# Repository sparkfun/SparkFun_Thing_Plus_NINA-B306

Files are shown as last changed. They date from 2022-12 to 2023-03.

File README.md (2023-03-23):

# SparkFun Thing Plus - NINA-B306

SparkFun Thing Plus - NINA-B306 (https://www.sparkfun.com/products/20854)

[SparkFun Thing Plus - NINA-B306 (WRL-20854)](https://www.sparkfun.com/products/20854)

The SparkFun Thing Plus - NINA-B306 offers a unique combination development platform in the Thing Plus form factor featuring the NINA-B306 from u-blox<sup>&trade;</sup>, the ISM330DHCX 6 DoF IMU from STMicroelectronics<sup>&trade;</sup> and the BME280 atmospheric sensor from Bosch Sensortec<sup>&trade;</sup>.

The NINA-B306 is a combination Bluetooth<sup>&trade;</sup> 5 module with an Arm<sup>&reg;</sup> Cortex<sup>&reg;</sup>-M4 processor. The NINA-B306 features an integrated PCB antenna removing the need for any external antenna. It includes 1 MB Flash and 250 kB RAM.

The BME280 combined humidity and pressure sensor measures barometric pressure, humidity and ambient temperature in a small package. The sensor measures pressure from 300 to 1100 hPa and has a full temperature accuracy range from 0 to 65&deg;C. The sensor communicates with the NINA-B306 over I<sup>2</sup>C.

The ISM330DHCX 6DoF IMU is a high-performance 3D digital accelerometer and 3D digital gyroscope tailored for Industry 4.0. The IMU has full scale user selectable acceleration ranges of &plusmn;2/&plusmn;4/&plusmn;8/&plusmn;16g and wide angular rate ranges of &plusmn;125/&plusmn;250/&plusmn;500/&plusmn;1000/&plusmn;2000/&plusmn;4000dps. The ISM330DHCX has embedded features including Machine Learning Core<sup><a href="#IMU_Mode">1</a></b></sup>, programmable FSM, FIFO, sensor hub, event decoding, and interrupts.

## Repository Contents

- **/Documentation** - Data sheets, additional product information
- **/Firmware** - Example code
- **/Hardware** - Eagle design files (.brd, .sch)
- **/Production** - Production panel files (.brd)

## Documentation

- **[BME280 Library](https://github.com/sparkfun/SparkFun_BME280_Arduino_Library)** - Arduino library for the BME280.
- **[ISM330DHCX Library](https://github.com/sparkfun/SparkFun_6DoF_ISM330DHCX_Arduino_Library)** - Arduino library for the ISM330DHCX.
- **[MAX17048 Library](https://github.com/sparkfun/SparkFun_MAX1704x_Fuel_Gauge_Arduino_Library)** - Arduino library for the MAX1704X.
- **[Hookup Guide](https://learn.sparkfun.com/tutorials/sparkfun-thing-plus---nina-b306-hookup-guide)** - Basic hookup guide for the SparkFun Thing Plus - NINA-B306.

## Product Versions

- [WRL-20854](https://www.sparkfun.com/products/20854) - Initial release of the SparkFun Thing Plus - NINA-B306.

## License Information

This product is _**open source**_!

Please review the LICENSE.md file for license information.

If you have any questions or concerns on licensing, please contact technical support on our [SparkFun forums](https://forum.sparkfun.com/viewforum.php?f=152).

Distributed as-is; no warranty is given.

- Your friends at SparkFun.

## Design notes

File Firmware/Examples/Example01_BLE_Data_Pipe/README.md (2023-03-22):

# Example01 BLE Data Pipe Demo arduino-cli flash command

From `$REPO/Firmware/Examples/Example01_BLE_Data_Pipe`:

## Locally downloaded Repo and Library

```bash
arduino-cli.exe compile --library /absolute/path/to/library/SparkFun_Thing_Plus_NINA-B306/libraries/SparkFunBLEService -b arduino-git:Adafruit_nRF52_Arduino:sfe_thingplus_ninab306 -e --port $COMPORT --upload Example01_BLE_Data_Pipe.ino
```

## Arduino Library

```bash
arduino-cli.exe compile -b adafruit:nrf52:sfe_thingplus_ninab306 -e --port $COMPORT --upload Example01_BLE_Data_Pipe.ino
```

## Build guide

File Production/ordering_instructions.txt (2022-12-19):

panel size, 131x154mm
PCB thickness, 1.6mm
number of layers, 4
soldermask color, Red
silkscreen color, White
oz copper, 1oz
finish, HASL lead free
stencils, top+bottom
pcs per panel, 10
min trace width, 0.1500mm / 0.0059in
min drill size, 0.3000mm / 0.0118in
filename to layer stackup 1/2/3/4: GTL, GL2, GL3, GBL

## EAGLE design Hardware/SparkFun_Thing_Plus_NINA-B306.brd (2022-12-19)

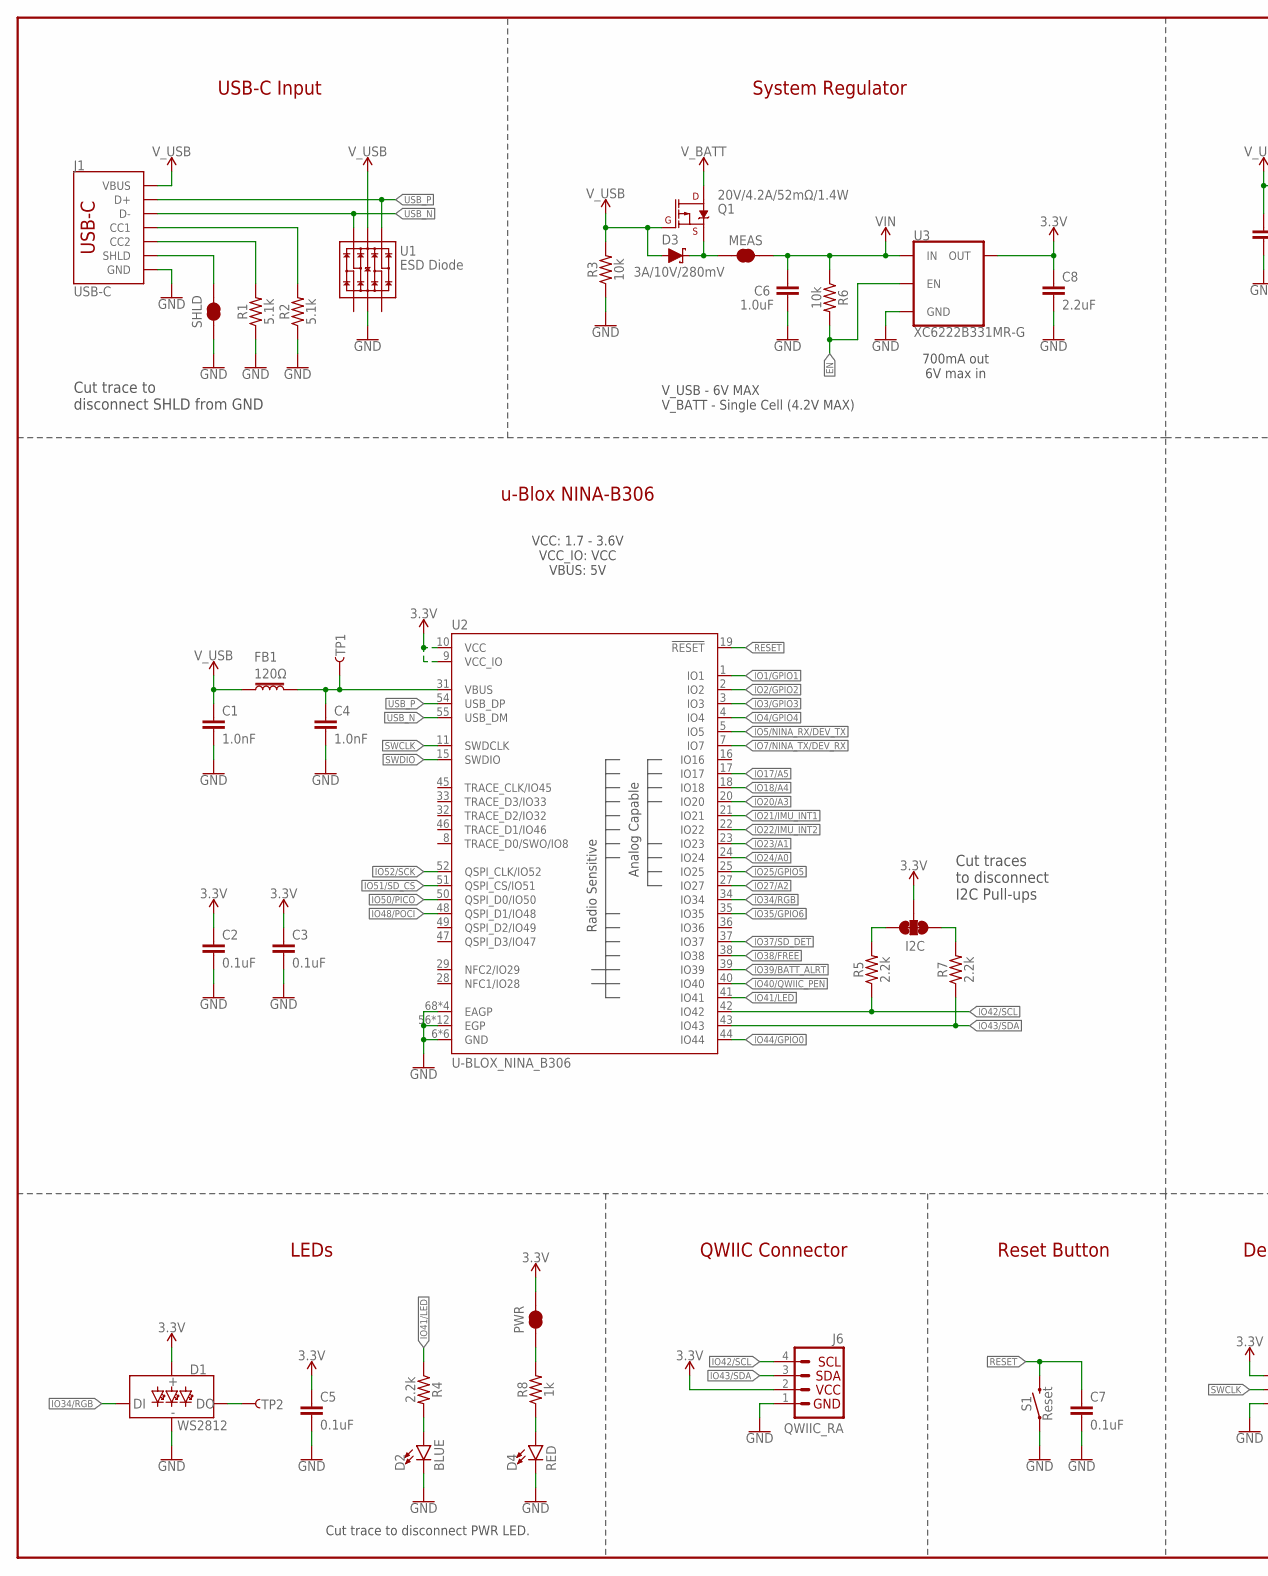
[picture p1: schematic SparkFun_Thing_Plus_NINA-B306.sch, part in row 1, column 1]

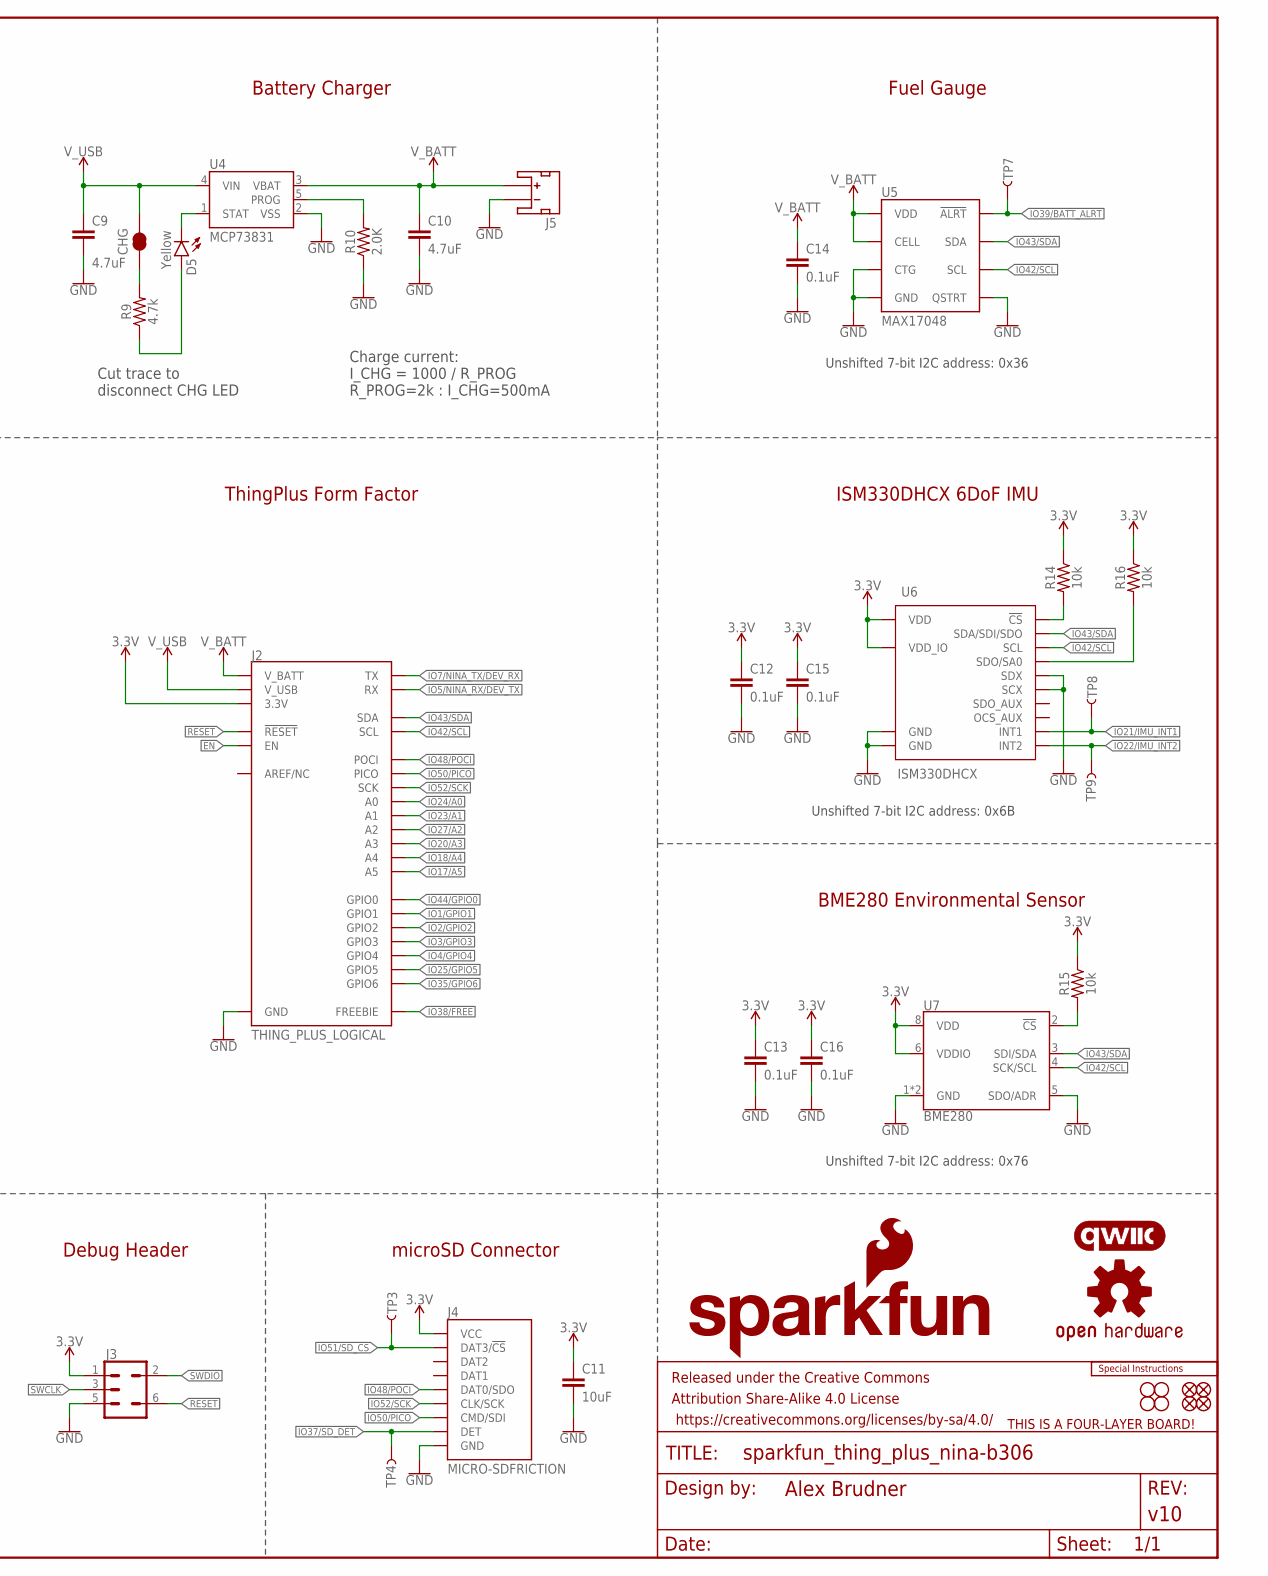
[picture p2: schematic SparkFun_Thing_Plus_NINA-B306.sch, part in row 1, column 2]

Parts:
C1, C4: 1.0nF; 0402-TIGHT
C2, C3, C5, C7, C12, C13, C14, C15, C16: 0.1uF; 0402-TIGHT
C6: 1.0uF; 0402-TIGHT
C8: 2.2uF; 0402-TIGHT
C9, C10: 4.7uF; 0402-TIGHT
C11: 10uF; 0402-TIGHT
CHG: JUMPER-SMT_2_NC_TRACE_SILK; SMT-JUMPER_2_NC_TRACE_SILK
D1: WS2812; WS2812-2020
D2: BLUE; LED-0603
D3: 3A/10V/280mV; SOD-323
D4: RED; LED-0603
D5: Yellow; LED-0603
FB1: 120Ω; 0402
FD1, FD2, FD3, FD4: FIDUCIALUFIDUCIAL; FIDUCIAL-MICRO
FRAME1: FRAME-LEDGER; CREATIVE_COMMONS
H1, H2, H3, H4: STAND-OFFTIGHT; STAND-OFF-TIGHT
I2C: JUMPER-SMT_3_2-NC_TRACE_SILK; SMT-JUMPER_3_2-NC_TRACE_SILK
J1: USB-C; USB-C-16P-4LAYER-ISOLATED
J2: THING_PLUS_LOGICAL; THING_PLUS
J3: CONN_03X2_NO4; PAD_05_03X2_TP_NO4
J4: MICRO-SDFRICTION; MICROSD_TINY
J5: JST_2MM_MALE; JST-2-SMD
J6: QWIIC_RA; JST04_1MM_RA
LOGO1: SFE_LOGO_NAME_FLAME.1_INCH; SFE_LOGO_NAME_FLAME_.1
LOGO2: FOUR_LAYER_WARNING
LOGO3: SPECIAL_INSTRUCTIONS-ORDERING; ORDERING_INSTRUCTIONS
LOGO4: QWIIC_LOGO_4MM; QWIIC_4MM
LOGO5: OSHW-LOGOMINI; OSHW-LOGO-MINI
MEAS: JUMPER-COMBO_2_NC_TRACE; COMBO-JUMPER_2_NC_TRACE
PWR: JUMPER-SMT_2_NC_TRACE_SILK; SMT-JUMPER_2_NC_TRACE_SILK
Q1: 20V/4.2A/52mΩ/1.4W; SOT23-3
R1, R2: 5.1k; 0402-TIGHT
R3, R6, R14, R15, R16: 10k; 0402-TIGHT
R4, R5, R7: 2.2k; 0402-TIGHT
R8: 1k; 0402-TIGHT
R9: 4.7k; 0402-TIGHT
R10: 2.0K; 0402-TIGHT
S1: Reset; TACTILE_SWITCH_SMD_4.6X2.8MM
SHLD: JUMPER-SMT_2_NC_TRACE_SILK; SMT-JUMPER_2_NC_TRACE_SILK
TP1, TP2, TP3, TP4, TP7, TP8, TP9: TEST-POINT3X5; PAD.03X.05
U1: ESD Diode; SOT-23-6
U2: U-BLOX_NINA_B306; NINA_B306
U3: XC6222B331MR-G; SOT23-5
U4: MCP73831; SOT23-5
U5: MAX17048; DFN-8
U6: ISM330DHCX; LGA-14L
U7: BME280; LGA-8-2.5X2.5

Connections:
3.3V: C2.1, C3.1, C5.1, C8.1, C11.1, C12.1, C13.1, C15.1, C16.1, D1.VCC, I2C.2, J2.27 (3.3V), J3.1, J4.4 (VCC), J6.2, PWR.2, R14.1, R15.1, R16.1, U2.9 (VCC_IO), U2.10 (VCC), U3.5 (OUT), U6.P5 (VDD_IO), U6.P8 (VDD), U7.6 (VDDIO), U7.8 (VDD)
!RESET!: C7.1, J2.28 (!RESET), J3.6, S1.3 (2), S1.4 (2), U2.19 (!RESET!)
EN: J2.11 (EN), R6.2, U3.3 (EN)
GND: C1.2, C2.2, C3.2, C4.2, C5.2, C6.2, C7.2, C8.2, C9.2, C10.2, C11.2, C12.2, C13.2, C14.2, C15.2, C16.2, D1.GND, D2.C, D4.C, J1.GND, J1.GND2 (GND), J2.25 (GND), J3.5, J4.6 (GND), J4.GND1 (GND), J4.GND2 (GND), J4.GND3 (GND), J4.GND4 (GND), J4.GND5 (GND), J4.GND6 (GND), J5.1 (-), J6.1, R1.1, R2.1, R3.1, R10.1, S1.1, S1.2 (1), SHLD.1, U1.2 (VSS), U2.6 (GND), U2.12 (GND), U2.14 (GND), U2.26 (GND), U2.30 (GND), U2.53 (GND), U2.56 (EGP), U2.57 (EGP), U2.58 (EGP), U2.59 (EGP), U2.60 (EGP), U2.61 (EGP), U2.62 (EGP), U2.63 (EGP), U2.64 (EGP), U2.65 (EGP), U2.66 (EGP), U2.67 (EGP), U2.68 (EAGP), U2.69 (EAGP), U2.70 (EAGP), U2.71 (EAGP), U3.2 (GND), U4.2 (VSS), U5.1 (CTG), U5.4 (GND), U5.6 (QSTRT), U5.9 (GND), U6.P2 (SDX), U6.P3 (SCX), U6.P6 (GND), U6.P7 (GND), U7.1 (GND), U7.5 (SDO/ADR), U7.7 (GND)
IO1/GPIO1: J2.8 (GPIO1), U2.1 (IO1)
IO2/GPIO2: J2.7 (GPIO2), U2.2 (IO2)
IO3/GPIO3: J2.6 (GPIO3), U2.3 (IO3)
IO4/GPIO4: J2.5 (GPIO4), U2.4 (IO4)
IO5/NINA_RX/DEV_TX: J2.15 (RX), U2.5 (IO5)
IO7/NINA_TX/DEV_RX: J2.14 (TX), U2.7 (IO7)
IO17/A5: J2.19 (A5), U2.17 (IO17)
IO18/A4: J2.20 (A4), U2.18 (IO18)
IO20/A3: J2.21 (A3), U2.20 (IO20)
IO21/IMU_INT1: TP8.1, U2.21 (IO21), U6.P4 (INT1)
IO22/IMU_INT2: TP9.1, U2.22 (IO22), U6.P9 (INT2)
IO23/A1: J2.23 (A1), U2.23 (IO23)
IO24/A0: J2.24 (A0), U2.24 (IO24)
IO25/GPIO5: J2.4 (GPIO5), U2.25 (IO25)
IO27/A2: J2.22 (A2), U2.27 (IO27)
IO34/RGB: D1.DI, U2.34 (IO34)
IO35/GPIO6: J2.3 (GPIO6), U2.35 (IO35)
IO37/SD_DET: J4.9 (DET), TP4.1, U2.37 (IO37)
IO38/FREE: J2.13 (FREEBIE), U2.38 (IO38)
IO39/!BATT_ALRT!: TP7.1, U2.39 (IO39), U5.5 (!ALRT)
IO40/QWIIC_!PEN!: U2.40 (IO40)
IO41/LED: R4.1, U2.41 (IO41)
IO42/SCL: J2.2 (SCL), J6.4, R5.1, U2.42 (IO42), U5.7 (SCL), U6.P13 (SCL), U7.4 (SCK/SCL)
IO43/SDA: J2.1 (SDA), J6.3, R7.1, U2.43 (IO43), U5.8 (SDA), U6.P14 (SDA/SDI/SDO), U7.3 (SDI/SDA)
IO44/GPIO0: J2.9 (GPIO0), U2.44 (IO44)
IO48/POCI: J2.16 (POCI), J4.7 (DAT0/SDO), U2.48 (QSPI_D1/IO48)
IO50/PICO: J2.17 (PICO), J4.3 (CMD/SDI), U2.50 (QSPI_D0/IO50)
IO51/SD_!CS!: J4.2 (DAT3/!CS!), TP3.1, U2.51 (QSPI_CS/IO51)
IO52/SCK: J2.18 (SCK), J4.5 (CLK/SCK), U2.52 (QSPI_CLK/IO52)
unnamed: J1.B5 (CC2), R1.2
unnamed: J1.A5 (CC1), R2.2
unnamed: D5.A, R9.1
unnamed: D5.C, U4.1 (STAT)
unnamed: R10.2, U4.5 (PROG)
unnamed: CHG.1, R9.2
unnamed: D4.A, R8.1
unnamed: PWR.1, R8.2
unnamed: D3.C, MEAS.1, MEAS.3 (1), Q1.2 (S)
unnamed: D1.DO, TP2.1
unnamed: R15.2, U7.2 (!CS)
unnamed: D2.A, R4.2
unnamed: R14.2, U6.P12 (!CS!)
unnamed: R16.2, U6.P1 (SDO/SA0)
unnamed: C4.1, FB1.2, TP1.1, U2.31 (VBUS)
SCL_PU_PWR: I2C.3, R5.2
SDA_PU_PWR: I2C.1, R7.2
SHLD: J1.SHLD1 (SHLD), J1.SHLD2 (SHLD), J1.SHLD3 (SHLD), J1.SHLD4 (SHLD), J1.SHLD5 (SHLD), J1.SHLD6 (SHLD), J1.SHLD7 (SHLD), J1.SHLD8 (SHLD), SHLD.2
SWCLK: J3.3, U2.11 (SWDCLK)
SWDIO: J3.2, U2.15 (SWDIO)
USB_N: J1.A7 (D-), J1.B7 (D-), U1.6 (IO4), U2.55 (USB_DM)
USB_P: J1.A6 (D+), J1.B6 (D+), U1.4 (IO3), U2.54 (USB_DP)
VIN: C6.1, MEAS.2, MEAS.4 (2), R6.1, U3.1 (IN)
V_BATT: C10.1, C14.1, J2.12 (V_BATT), J5.2 (+), Q1.3 (D), U4.3 (VBAT), U5.2 (CELL), U5.3 (VDD)
V_USB: C1.1, C9.1, CHG.2, D3.A, FB1.1, J1.VBUS1 (VBUS), J1.VBUS2 (VBUS), J2.10 (V_USB), Q1.1 (G), R3.2, U1.5 (VCC), U4.4 (VIN)

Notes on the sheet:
Battery Charger
Cut trace to disconnect CHG LED
Charge current: I_CHG = 1000 / R_PROG R_PROG=2k : I_CHG=500mA
System Regulator
700mA out 6V max in
V_USB - 6V MAX V_BATT - Single Cell (4.2V MAX)
USB-C Input
Fuel Gauge
Unshifted 7-bit I2C address: 0x36
Cut trace to disconnect SHLD from GND
microSD Connector
Debug Header
LEDs
Reset Button
u-Blox NINA-B306
ThingPlus Form Factor
QWIIC Connector
Cut traces to disconnect I2C Pull-ups
BME280 Environmental Sensor
Unshifted 7-bit I2C address: 0x76
Unshifted 7-bit I2C address: 0x6B
ISM330DHCX 6DoF IMU
VCC: 1.7 - 3.6V VCC_IO: VCC VBUS: 5V
Cut trace to disconnect PWR LED.

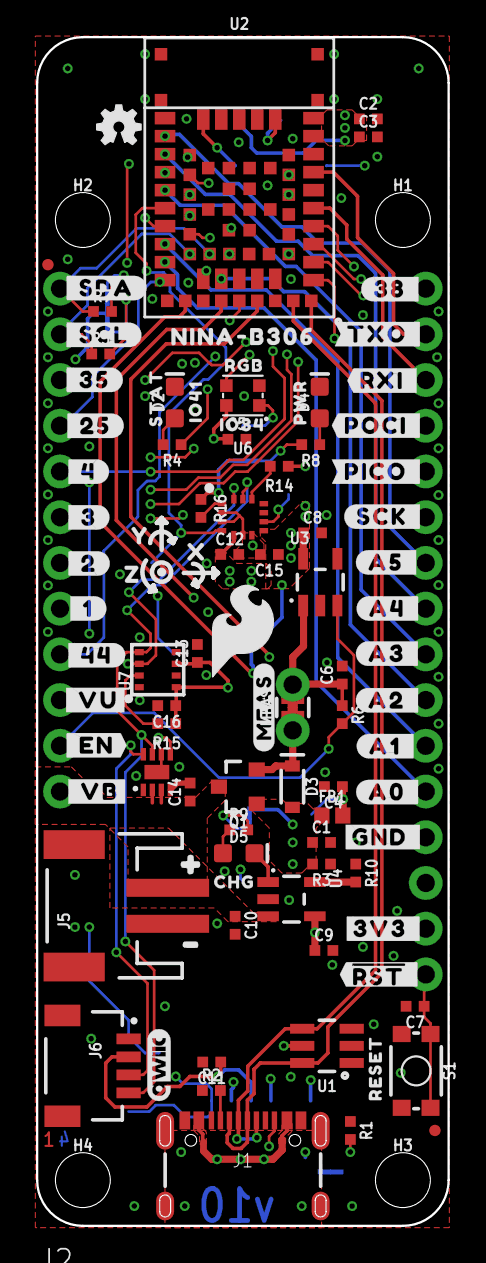
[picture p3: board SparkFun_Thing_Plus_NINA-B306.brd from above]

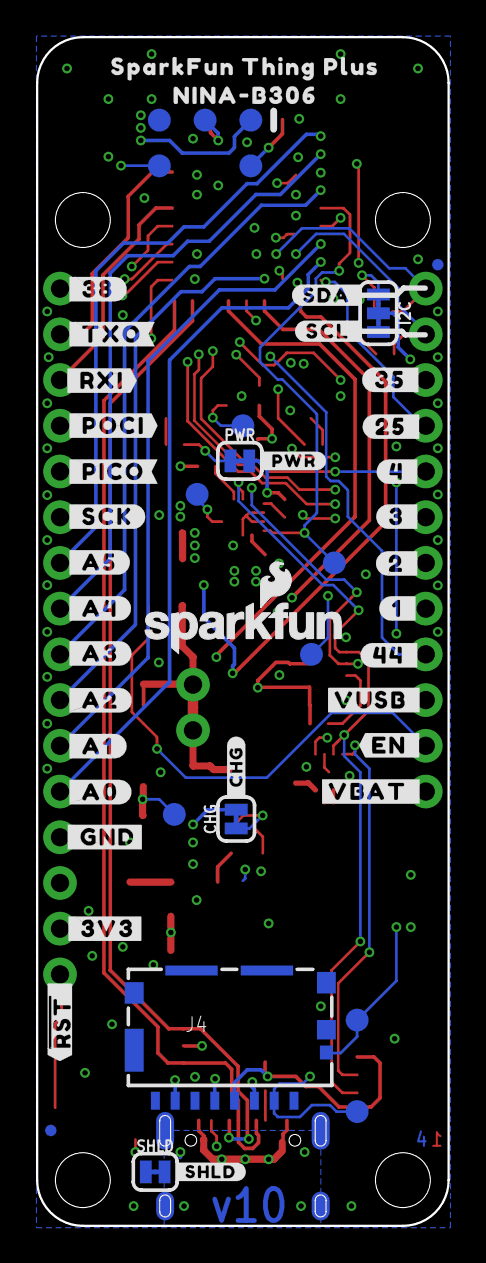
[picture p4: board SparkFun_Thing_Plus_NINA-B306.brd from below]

Board: 4 copper layers, 22.9 x 66.0 mm, 151 parts (49 on the bottom side), 57 nets.

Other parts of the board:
U$1: SFE_LOGO_FLAME_STOP_.1
U$2: SFE_LOGO_FLAME_.2
U$3: #_VU#0
U$4: #_EN#47
U$5: #3V3_#0
U$6: #_44#49
U$7: #_1#49
U$8: #_2#49
U$9: #_3#49
U$10: #_4#49
U$11: #_25#49
U$12: #_35#0
U$13: #_SCL#49
U$14: RESET0
U$16: #GND_#53
U$17: #A0_#54
U$18: #A1_#54
U$19: #A2_#54
U$20: #A3_#54
U$21: #A4_#54
U$22: #A5_#54
U$23: #SCK_#54
U$24: #PICO_#60
U$25: #POCI_#61
U$26: #TXO_#57
U$27: #RXI_#59
U$28: #38_#60
U$29: #_SDA#68
U$30: #_CHG#30707
U$31: #_3V3#0
U$32: #_GND#70
U$33: #_A0#71
U$34: #_A1#71
U$35: #_A2#71
U$36: #_A3#71
U$37: #_A4#71
U$38: #_A5#71
U$39: #_SCK#71
U$40: #_PICO#72
U$41: #_POCI#73
U$42: #_TXO#74
U$43: #_RXI#75
U$44: #_38#76
U$45: #35_#0
U$46: #25_#79
U$47: #4_#79
U$48: #3_#79
U$49: #2_#79
U$50: #1_#79
U$51: #44_#79
U$52: #VBAT_#0
U$53: #EN_#80
U$54, U$74: ##RST#_#0
U$55: #SDA_#82
U$56: #SCL_#85
U$57: #_PWR#90
U$58: #VUSB_#0
U$59: #_SHLD#93
U$60: SPARKFUN_THING_PLUS96
U$61: NINA#B30697
U$62: #MEAS#30701
U$63: #_VB#0
U$64: RGB30710
U$65: STAT30711
U$66: PWR30712
U$67: NINA#B30630713
U$68: X2114
U$69: Y2115
U$70: Z2116
U$71: IO414130630715
U$72: IO34414130630716
U$73: CHG0
U$75: #3
U$76: #4

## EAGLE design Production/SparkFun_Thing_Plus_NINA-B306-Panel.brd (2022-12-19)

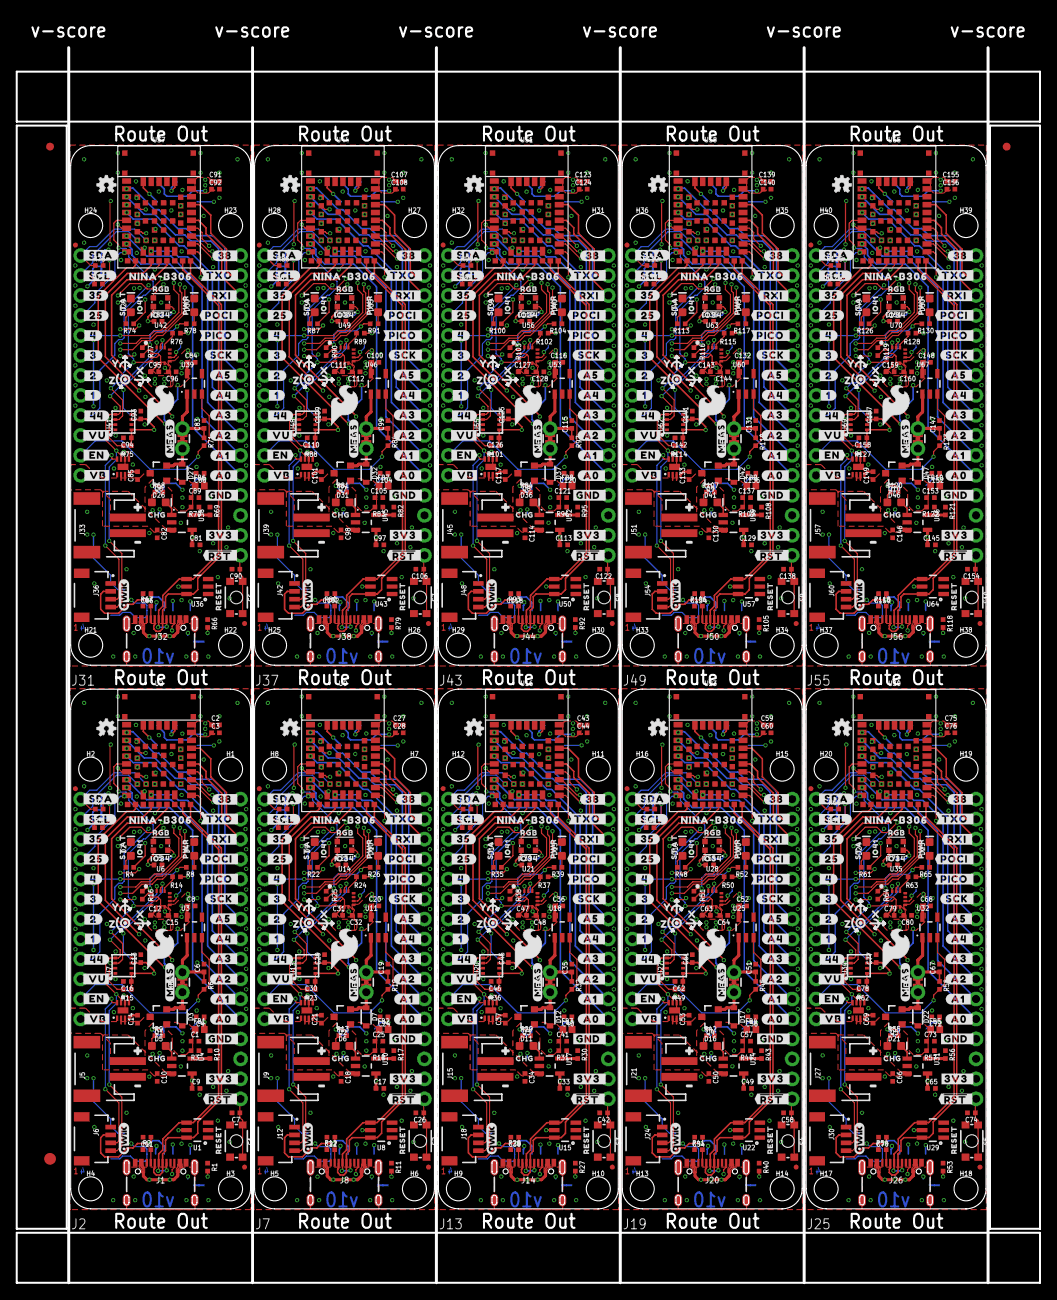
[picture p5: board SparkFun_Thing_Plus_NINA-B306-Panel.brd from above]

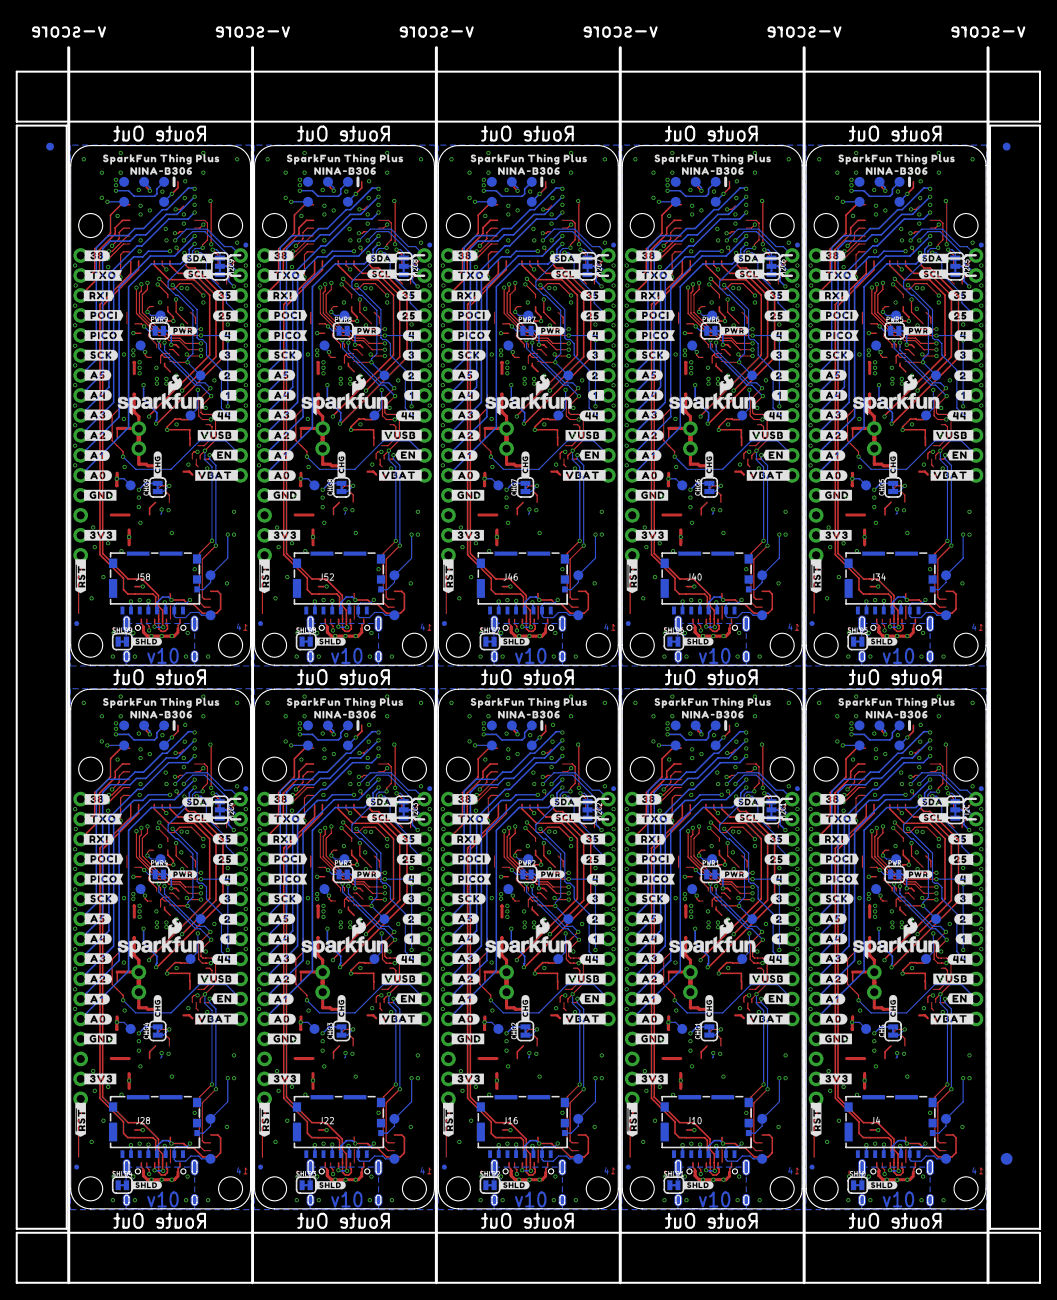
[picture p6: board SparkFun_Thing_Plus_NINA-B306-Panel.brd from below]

Board: 4 copper layers, 130.0 x 157.0 mm, 1506 parts (493 on the bottom side), 570 nets.

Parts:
C1, C4, C24, C25, C40, C41, C56, C57, C72, C73, C88, C89, C104, C105, C120, C121, C136, C137, C152, C153: 1.0nF; 0402-TIGHT
C2, C3, C5, C7, C12, C13, C14, C15, C16, C21, C23, C26, C27, C28, C29, C30, C31, C32, C37, C39, C42, C43, C44, C45, C46, C47, C48, C53, C55, C58, C59, C60, C61, C62, C63, C64, C69, C71, C74, C75, C76, C77, C78, C79, C80, C85, C87, C90, C91, C92, C93, C94, C95, C96, C101, C103, C106, C107, C108, C109, C110, C111, C112, C117, C119, C122, C123, C124, C125, C126, C127, C128, C133, C135, C138, C139, C140, C141, C142, C143, C144, C149, C151, C154, C155, C156, C157, C158, C159, C160: 0.1uF; 0402-TIGHT
C6, C19, C35, C51, C67, C83, C99, C115, C131, C147: 1.0uF; 0402-TIGHT
C8, C20, C36, C52, C68, C84, C100, C116, C132, C148: 2.2uF; 0402-TIGHT
C9, C10, C17, C18, C33, C34, C49, C50, C65, C66, C81, C82, C97, C98, C113, C114, C129, C130, C145, C146: 4.7uF; 0402-TIGHT
C11, C22, C38, C54, C70, C86, C102, C118, C134, C150: 10uF; 0402-TIGHT
CHG, CHG1, CHG2, CHG3, CHG4, CHG5, CHG6, CHG7, CHG8, CHG9: JUMPER-SMT_2_NC_TRACE_SILK; SMT-JUMPER_2_NC_TRACE_SILK
D1, D8, D13, D18, D23, D28, D33, D38, D43, D48: WS2812; WS2812-2020
D2, D9, D14, D19, D24, D29, D34, D39, D44, D49: BLUE; LED-0603
D3, D7, D12, D17, D22, D27, D32, D37, D42, D47: 3A/10V/280mV; SOD-323
D4, D10, D15, D20, D25, D30, D35, D40, D45, D50: RED; LED-0603
D5, D6, D11, D16, D21, D26, D31, D36, D41, D46: Yellow; LED-0603
E$1, E$2, E$3, E$4: FIDUCIAL-1X2
E$5, E$6: FIDUCIAL-1.5X3
FB1, FB2, FB3, FB4, FB5, FB6, FB7, FB8, FB9, FB10: 120Ω; 0402
FD1, FD2, FD3, FD4, FD5, FD6, FD7, FD8, FD9, FD10, FD11, FD12, FD13, FD14, FD15, FD16, FD17, FD18, FD19, FD20, FD21, FD22, FD23, FD24, FD25, FD26, FD27, FD28, FD29, FD30, FD31, FD32, FD33, FD34, FD35, FD36, FD37, FD38, FD39, FD40: FIDUCIALUFIDUCIAL; FIDUCIAL-MICRO
H1, H2, H3, H4, H5, H6, H7, H8, H9, H10, H11, H12, H13, H14, H15, H16, H17, H18, H19, H20, H21, H22, H23, H24, H25, H26, H27, H28, H29, H30, H31, H32, H33, H34, H35, H36, H37, H38, H39, H40: STAND-OFFTIGHT; STAND-OFF-TIGHT
I2C, I2C1, I2C2, I2C3, I2C4, I2C5, I2C6, I2C7, I2C8, I2C9: JUMPER-SMT_3_2-NC_TRACE_SILK; SMT-JUMPER_3_2-NC_TRACE_SILK
J1, J8, J14, J20, J26, J32, J38, J44, J50, J56: USB-C; USB-C-16P-4LAYER-ISOLATED
J2, J7, J13, J19, J25, J31, J37, J43, J49, J55: THING_PLUS_LOGICAL; THING_PLUS
J3, J11, J17, J23, J29, J35, J41, J47, J53, J59: CONN_03X2_NO4; PAD_05_03X2_TP_NO4
J4, J10, J16, J22, J28, J34, J40, J46, J52, J58: MICRO-SDFRICTION; MICROSD_TINY
J5, J9, J15, J21, J27, J33, J39, J45, J51, J57: JST-2-SMD
J6, J12, J18, J24, J30, J36, J42, J48, J54, J60: QWIIC_RA; JST04_1MM_RA
LOGO1, LOGO6, LOGO11, LOGO16, LOGO21, LOGO26, LOGO31, LOGO36, LOGO41, LOGO46: SFE_LOGO_NAME_FLAME.1_INCH; SFE_LOGO_NAME_FLAME_.1
LOGO2, LOGO10, LOGO15, LOGO20, LOGO25, LOGO30, LOGO35, LOGO40, LOGO45, LOGO50: FOUR_LAYER_WARNING
LOGO3, LOGO8, LOGO13, LOGO18, LOGO23, LOGO28, LOGO33, LOGO38, LOGO43, LOGO48: SPECIAL_INSTRUCTIONS-ORDERING; ORDERING_INSTRUCTIONS
LOGO4, LOGO9, LOGO14, LOGO19, LOGO24, LOGO29, LOGO34, LOGO39, LOGO44, LOGO49: QWIIC_LOGO_4MM; QWIIC_4MM
LOGO5, LOGO7, LOGO12, LOGO17, LOGO22, LOGO27, LOGO32, LOGO37, LOGO42, LOGO47: OSHW-LOGOMINI; OSHW-LOGO-MINI
MEAS, MEAS1, MEAS2, MEAS3, MEAS4, MEAS5, MEAS6, MEAS7, MEAS8, MEAS9: JUMPER-COMBO_2_NC_TRACE; COMBO-JUMPER_2_NC_TRACE
PWR, PWR1, PWR2, PWR3, PWR4, PWR5, PWR6, PWR7, PWR8, PWR9: JUMPER-SMT_2_NC_TRACE_SILK; SMT-JUMPER_2_NC_TRACE_SILK
Q1, Q2, Q3, Q4, Q5, Q6, Q7, Q8, Q9, Q10: 20V/4.2A/52mΩ/1.4W; SOT23-3
R1, R2, R11, R12, R27, R28, R40, R41, R53, R54, R66, R67, R79, R80, R92, R93, R105, R106, R118, R119: 5.1k; 0402-TIGHT
R3, R6, R14, R15, R16, R18, R19, R23, R24, R25, R31, R32, R36, R37, R38, R44, R45, R49, R50, R51, R57, R58, R62, R63, R64, R70, R71, R75, R76, R77, R83, R84, R88, R89, R90, R96, R97, R101, R102, R103, R109, R110, R114, R115, R116, R122, R123, R127, R128, R129: 10k; 0402-TIGHT
R4, R5, R7, R20, R21, R22, R33, R34, R35, R46, R47, R48, R59, R60, R61, R72, R73, R74, R85, R86, R87, R98, R99, R100, R111, R112, R113, R124, R125, R126: 2.2k; 0402-TIGHT
R8, R26, R39, R52, R65, R78, R91, R104, R117, R130: 1k; 0402-TIGHT
R9, R13, R29, R42, R55, R68, R81, R94, R107, R120: 4.7k; 0402-TIGHT
R10, R17, R30, R43, R56, R69, R82, R95, R108, R121: 2.0K; 0402-TIGHT
S1, S2, S3, S4, S5, S6, S7, S8, S9, S10: Reset; TACTILE_SWITCH_SMD_4.6X2.8MM
SHLD, SHLD1, SHLD2, SHLD3, SHLD4, SHLD5, SHLD6, SHLD7, SHLD8, SHLD9: SMT-JUMPER_2_NC_TRACE_SILK
TP1, TP2, TP3, TP4, TP5, TP6, TP7, TP8, TP9, TP10, TP11, TP12, TP13, TP14, TP15, TP16, TP17, TP18, TP19, TP20, TP21, TP22, TP23, TP24, TP25, TP26, TP27, TP28, TP29, TP30, TP31, TP32, TP33, TP34, TP35, TP36, TP37, TP38, TP39, TP40, TP41, TP42, TP43, TP44, TP45, TP46, TP47, TP48, TP49, TP50, TP51, TP52, TP53, TP54, TP55, TP56, TP57, TP58, TP59, TP60, TP61, TP62, TP63, TP64, TP65, TP66, TP67, TP68, TP69, TP70: TEST-POINT3X5; PAD.03X.05
U1, U8, U15, U22, U29, U36, U43, U50, U57, U64: ESD Diode; SOT-23-6
U2, U9, U16, U23, U30, U37, U44, U51, U58, U65: U-BLOX_NINA_B306; NINA_B306
U3, U11, U18, U25, U32, U39, U46, U53, U60, U67: XC6222B331MR-G; SOT23-5
U4, U10, U17, U24, U31, U38, U45, U52, U59, U66: MCP73831; SOT23-5
U5, U12, U19, U26, U33, U40, U47, U54, U61, U68: MAX17048; DFN-8
U6, U14, U21, U28, U35, U42, U49, U56, U63, U70: ISM330DHCX; LGA-14L
U7, U13, U20, U27, U34, U41, U48, U55, U62, U69: BME280; LGA-8-2.5X2.5
U$1, U$15, U$151, U$226, U$301, U$376, U$451, U$526, U$601, U$676: SFE_LOGO_FLAME_STOP_.1
U$2, U$77, U$152, U$227, U$302, U$377, U$452, U$527, U$602, U$677: SFE_LOGO_FLAME_.2
U$3, U$142, U$217, U$292, U$367, U$442, U$517, U$592, U$667, U$742: #_VU#0
U$4, U$78, U$153, U$228, U$303, U$378, U$453, U$528, U$603, U$678: #_EN#47
U$5, U$143, U$218, U$293, U$368, U$443, U$518, U$593, U$668, U$743: #3V3_#0
U$6, U$79, U$154, U$229, U$304, U$379, U$454, U$529, U$604, U$679: #_44#49
U$7, U$80, U$155, U$230, U$305, U$380, U$455, U$530, U$605, U$680: #_1#49
U$8, U$81, U$156, U$231, U$306, U$381, U$456, U$531, U$606, U$681: #_2#49
U$9, U$82, U$157, U$232, U$307, U$382, U$457, U$532, U$607, U$682: #_3#49
U$10, U$83, U$158, U$233, U$308, U$383, U$458, U$533, U$608, U$683: #_4#49
U$11, U$84, U$159, U$234, U$309, U$384, U$459, U$534, U$609, U$684: #_25#49
U$12, U$140, U$215, U$290, U$365, U$440, U$515, U$590, U$665, U$740: #_35#0
U$13, U$85, U$160, U$235, U$310, U$385, U$460, U$535, U$610, U$685: #_SCL#49
U$14, U$144, U$219, U$294, U$369, U$444, U$519, U$594, U$669, U$744: RESET0
U$16, U$86, U$161, U$236, U$311, U$386, U$461, U$536, U$611, U$686: #GND_#53
U$17, U$87, U$162, U$237, U$312, U$387, U$462, U$537, U$612, U$687: #A0_#54
U$18, U$88, U$163, U$238, U$313, U$388, U$463, U$538, U$613, U$688: #A1_#54
U$19, U$89, U$164, U$239, U$314, U$389, U$464, U$539, U$614, U$689: #A2_#54
U$20, U$90, U$165, U$240, U$315, U$390, U$465, U$540, U$615, U$690: #A3_#54
U$21, U$91, U$166, U$241, U$316, U$391, U$466, U$541, U$616, U$691: #A4_#54
U$22, U$92, U$167, U$242, U$317, U$392, U$467, U$542, U$617, U$692: #A5_#54
U$23, U$93, U$168, U$243, U$318, U$393, U$468, U$543, U$618, U$693: #SCK_#54
U$24, U$97, U$172, U$247, U$322, U$397, U$472, U$547, U$622, U$697: #PICO_#60
U$25, U$98, U$173, U$248, U$323, U$398, U$473, U$548, U$623, U$698: #POCI_#61
U$26, U$94, U$169, U$244, U$319, U$394, U$469, U$544, U$619, U$694: #TXO_#57
U$27, U$95, U$170, U$245, U$320, U$395, U$470, U$545, U$620, U$695: #RXI_#59
U$28, U$96, U$171, U$246, U$321, U$396, U$471, U$546, U$621, U$696: #38_#60
U$29, U$99, U$174, U$249, U$324, U$399, U$474, U$549, U$624, U$699: #_SDA#68
U$30, U$127, U$202, U$277, U$352, U$427, U$502, U$577, U$652, U$727: #_CHG#30707
U$31, U$147, U$222, U$297, U$372, U$447, U$522, U$597, U$672, U$747: #_3V3#0
U$32, U$100, U$175, U$250, U$325, U$400, U$475, U$550, U$625, U$700: #_GND#70
U$33, U$101, U$176, U$251, U$326, U$401, U$476, U$551, U$626, U$701: #_A0#71
U$34, U$102, U$177, U$252, U$327, U$402, U$477, U$552, U$627, U$702: #_A1#71
U$35, U$103, U$178, U$253, U$328, U$403, U$478, U$553, U$628, U$703: #_A2#71
U$36, U$104, U$179, U$254, U$329, U$404, U$479, U$554, U$629, U$704: #_A3#71
U$37, U$105, U$180, U$255, U$330, U$405, U$480, U$555, U$630, U$705: #_A4#71
U$38, U$106, U$181, U$256, U$331, U$406, U$481, U$556, U$631, U$706: #_A5#71
U$39, U$107, U$182, U$257, U$332, U$407, U$482, U$557, U$632, U$707: #_SCK#71
U$40, U$108, U$183, U$258, U$333, U$408, U$483, U$558, U$633, U$708: #_PICO#72
U$41, U$109, U$184, U$259, U$334, U$409, U$484, U$559, U$634, U$709: #_POCI#73
U$42, U$110, U$185, U$260, U$335, U$410, U$485, U$560, U$635, U$710: #_TXO#74
U$43, U$111, U$186, U$261, U$336, U$411, U$486, U$561, U$636, U$711: #_RXI#75
U$44, U$112, U$187, U$262, U$337, U$412, U$487, U$562, U$637, U$712: #_38#76
U$45, U$139, U$214, U$289, U$364, U$439, U$514, U$589, U$664, U$739: #35_#0
U$46, U$113, U$188, U$263, U$338, U$413, U$488, U$563, U$638, U$713: #25_#79
U$47, U$114, U$189, U$264, U$339, U$414, U$489, U$564, U$639, U$714: #4_#79
U$48, U$115, U$190, U$265, U$340, U$415, U$490, U$565, U$640, U$715: #3_#79
U$49, U$116, U$191, U$266, U$341, U$416, U$491, U$566, U$641, U$716: #2_#79
U$50, U$117, U$192, U$267, U$342, U$417, U$492, U$567, U$642, U$717: #1_#79
U$51, U$118, U$193, U$268, U$343, U$418, U$493, U$568, U$643, U$718: #44_#79
U$52, U$146, U$221, U$296, U$371, U$446, U$521, U$596, U$671, U$746: #VBAT_#0
U$53, U$119, U$194, U$269, U$344, U$419, U$494, U$569, U$644, U$719: #EN_#80
U$54, U$74, U$138, U$148, U$213, U$223, U$288, U$298, U$363, U$373, U$438, U$448, U$513, U$523, U$588, U$598, U$663, U$673, U$738, U$748: ##RST#_#0
U$55, U$120, U$195, U$270, U$345, U$420, U$495, U$570, U$645, U$720: #SDA_#82
U$56, U$121, U$196, U$271, U$346, U$421, U$496, U$571, U$646, U$721: #SCL_#85
U$57, U$122, U$197, U$272, U$347, U$422, U$497, U$572, U$647, U$722: #_PWR#90
U$58, U$145, U$220, U$295, U$370, U$445, U$520, U$595, U$670, U$745: #VUSB_#0
U$59, U$123, U$198, U$273, U$348, U$423, U$498, U$573, U$648, U$723: #_SHLD#93
U$60, U$124, U$199, U$274, U$349, U$424, U$499, U$574, U$649, U$724: SPARKFUN_THING_PLUS96
U$61, U$125, U$200, U$275, U$350, U$425, U$500, U$575, U$650, U$725: NINA#B30697
U$62, U$126, U$201, U$276, U$351, U$426, U$501, U$576, U$651, U$726: #MEAS#30701
U$63, U$141, U$216, U$291, U$366, U$441, U$516, U$591, U$666, U$741: #_VB#0
U$64, U$128, U$203, U$278, U$353, U$428, U$503, U$578, U$653, U$728: RGB30710
U$65, U$129, U$204, U$279, U$354, U$429, U$504, U$579, U$654, U$729: STAT30711
U$66, U$130, U$205, U$280, U$355, U$430, U$505, U$580, U$655, U$730: PWR30712
U$67, U$131, U$206, U$281, U$356, U$431, U$506, U$581, U$656, U$731: NINA#B30630713
U$68, U$132, U$207, U$282, U$357, U$432, U$507, U$582, U$657, U$732: X2114
U$69, U$133, U$208, U$283, U$358, U$433, U$508, U$583, U$658, U$733: Y2115
U$70, U$134, U$209, U$284, U$359, U$434, U$509, U$584, U$659, U$734: Z2116
U$71, U$135, U$210, U$285, U$360, U$435, U$510, U$585, U$660, U$735: IO414130630715
U$72, U$136, U$211, U$286, U$361, U$436, U$511, U$586, U$661, U$736: IO34414130630716
U$73, U$137, U$212, U$287, U$362, U$437, U$512, U$587, U$662, U$737: CHG0
U$75, U$149, U$224, U$299, U$374, U$449, U$524, U$599, U$674, U$749: #3
U$76, U$150, U$225, U$300, U$375, U$450, U$525, U$600, U$675, U$750: #4

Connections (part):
3.3V: C2.1, C3.1, C5.1, C8.1, C11.1, C12.1, C13.1, C15.1, C16.1, D1.VCC, I2C.2, J2.27, J3.1, J4.4, J6.2, PWR.2, R14.1, R15.1, R16.1, U2.9, U2.10, U3.5, U6.P5, U6.P8, U7.6, U7.8
3.3V1: C20.1, C22.1, C23.1, C27.1, C28.1, C29.1, C30.1, C31.1, C32.1, D8.VCC, I2C1.2, J7.27, J10.4, J11.1, J12.2, PWR1.2, R23.1, R24.1, R25.1, U9.9, U9.10, U11.5, U13.6, U13.8, U14.P5, U14.P8
3.3V2: C36.1, C38.1, C39.1, C43.1, C44.1, C45.1, C46.1, C47.1, C48.1, D13.VCC, I2C2.2, J13.27, J16.4, J17.1, J18.2, PWR2.2, R36.1, R37.1, R38.1, U16.9, U16.10, U18.5, U20.6, U20.8, U21.P5, U21.P8
3.3V3: C52.1, C54.1, C55.1, C59.1, C60.1, C61.1, C62.1, C63.1, C64.1, D18.VCC, I2C3.2, J19.27, J22.4, J23.1, J24.2, PWR3.2, R49.1, R50.1, R51.1, U23.9, U23.10, U25.5, U27.6, U27.8, U28.P5, U28.P8
3.3V4: C68.1, C70.1, C71.1, C75.1, C76.1, C77.1, C78.1, C79.1, C80.1, D23.VCC, I2C4.2, J25.27, J28.4, J29.1, J30.2, PWR4.2, R62.1, R63.1, R64.1, U30.9, U30.10, U32.5, U34.6, U34.8, U35.P5, U35.P8
3.3V5: C84.1, C86.1, C87.1, C91.1, C92.1, C93.1, C94.1, C95.1, C96.1, D28.VCC, I2C5.2, J31.27, J34.4, J35.1, J36.2, PWR5.2, R75.1, R76.1, R77.1, U37.9, U37.10, U39.5, U41.6, U41.8, U42.P5, U42.P8
3.3V6: C100.1, C102.1, C103.1, C107.1, C108.1, C109.1, C110.1, C111.1, C112.1, D33.VCC, I2C6.2, J37.27, J40.4, J41.1, J42.2, PWR6.2, R88.1, R89.1, R90.1, U44.9, U44.10, U46.5, U48.6, U48.8, U49.P5, U49.P8
3.3V7: C116.1, C118.1, C119.1, C123.1, C124.1, C125.1, C126.1, C127.1, C128.1, D38.VCC, I2C7.2, J43.27, J46.4, J47.1, J48.2, PWR7.2, R101.1, R102.1, R103.1, U51.9, U51.10, U53.5, U55.6, U55.8, U56.P5, U56.P8
3.3V8: C132.1, C134.1, C135.1, C139.1, C140.1, C141.1, C142.1, C143.1, C144.1, D43.VCC, I2C8.2, J49.27, J52.4, J53.1, J54.2, PWR8.2, R114.1, R115.1, R116.1, U58.9, U58.10, U60.5, U62.6, U62.8, U63.P5, U63.P8
3.3V9: C148.1, C150.1, C151.1, C155.1, C156.1, C157.1, C158.1, C159.1, C160.1, D48.VCC, I2C9.2, J55.27, J58.4, J59.1, J60.2, PWR9.2, R127.1, R128.1, R129.1, U65.9, U65.10, U67.5, U69.6, U69.8, U70.P5, U70.P8
!RESET!: C7.1, J2.28, J3.6, S1.3, S1.4, U2.19
!RESET!1: C26.1, J7.28, J11.6, S2.3, S2.4, U9.19
!RESET!2: C42.1, J13.28, J17.6, S3.3, S3.4, U16.19
!RESET!3: C58.1, J19.28, J23.6, S4.3, S4.4, U23.19
!RESET!4: C74.1, J25.28, J29.6, S5.3, S5.4, U30.19
!RESET!5: C90.1, J31.28, J35.6, S6.3, S6.4, U37.19
!RESET!6: C106.1, J37.28, J41.6, S7.3, S7.4, U44.19
!RESET!7: C122.1, J43.28, J47.6, S8.3, S8.4, U51.19
!RESET!8: C138.1, J49.28, J53.6, S9.3, S9.4, U58.19
!RESET!9: C154.1, J55.28, J59.6, S10.3, S10.4, U65.19
EN: J2.11, R6.2, U3.3
EN1: J7.11, R19.2, U11.3
EN2: J13.11, R32.2, U18.3
EN3: J19.11, R45.2, U25.3
EN4: J25.11, R58.2, U32.3
EN5: J31.11, R71.2, U39.3
EN6: J37.11, R84.2, U46.3
EN7: J43.11, R97.2, U53.3
EN8: J49.11, R110.2, U60.3
EN9: J55.11, R123.2, U67.3
GND: C1.2, C2.2, C3.2, C4.2, C5.2, C6.2, C7.2, C8.2, C9.2, C10.2, C11.2, C12.2, C13.2, C14.2, C15.2, C16.2, D1.GND, D2.C, D4.C, J1.GND, J1.GND2, J2.25, J3.5, J4.6, J4.GND1, J4.GND2, J4.GND3, J4.GND4, J4.GND5, J4.GND6, J5.1, J6.1, R1.1, R2.1, R3.1, R10.1, S1.1, S1.2, SHLD.1, U1.2, U2.6, U2.12, U2.14, U2.26, U2.30, U2.53, U2.56, U2.57, U2.58, U2.59, U2.60, U2.61, U2.62, U2.63, U2.64, U2.65, U2.66, U2.67, U2.68, U2.69, U2.70, U2.71, U3.2, U4.2, U5.1, U5.4, U5.6, U5.9, U6.P2, U6.P3, U6.P6, U6.P7, U7.1, U7.5, U7.7
GND1: C17.2, C18.2, C19.2, C20.2, C21.2, C22.2, C23.2, C24.2, C25.2, C26.2, C27.2, C28.2, C29.2, C30.2, C31.2, C32.2, D8.GND, D9.C, D10.C, J7.25, J8.GND, J8.GND2, J9.1, J10.6, J10.GND1, J10.GND2, J10.GND3, J10.GND4, J10.GND5, J10.GND6, J11.5, J12.1, R11.1, R12.1, R17.1, R18.1, S2.1, S2.2, SHLD1.1, U8.2, U9.6, U9.12, U9.14, U9.26, U9.30, U9.53, U9.56, U9.57, U9.58, U9.59, U9.60, U9.61, U9.62, U9.63, U9.64, U9.65, U9.66, U9.67, U9.68, U9.69, U9.70, U9.71, U10.2, U11.2, U12.1, U12.4, U12.6, U12.9, U13.1, U13.5, U13.7, U14.P2, U14.P3, U14.P6, U14.P7
GND2: C33.2, C34.2, C35.2, C36.2, C37.2, C38.2, C39.2, C40.2, C41.2, C42.2, C43.2, C44.2, C45.2, C46.2, C47.2, C48.2, D13.GND, D14.C, D15.C, J13.25, J14.GND, J14.GND2, J15.1, J16.6, J16.GND1, J16.GND2, J16.GND3, J16.GND4, J16.GND5, J16.GND6, J17.5, J18.1, R27.1, R28.1, R30.1, R31.1, S3.1, S3.2, SHLD2.1, U15.2, U16.6, U16.12, U16.14, U16.26, U16.30, U16.53, U16.56, U16.57, U16.58, U16.59, U16.60, U16.61, U16.62, U16.63, U16.64, U16.65, U16.66, U16.67, U16.68, U16.69, U16.70, U16.71, U17.2, U18.2, U19.1, U19.4, U19.6, U19.9, U20.1, U20.5, U20.7, U21.P2, U21.P3, U21.P6, U21.P7
GND3: C49.2, C50.2, C51.2, C52.2, C53.2, C54.2, C55.2, C56.2, C57.2, C58.2, C59.2, C60.2, C61.2, C62.2, C63.2, C64.2, D18.GND, D19.C, D20.C, J19.25, J20.GND, J20.GND2, J21.1, J22.6, J22.GND1, J22.GND2, J22.GND3, J22.GND4, J22.GND5, J22.GND6, J23.5, J24.1, R40.1, R41.1, R43.1, R44.1, S4.1, S4.2, SHLD3.1, U22.2, U23.6, U23.12, U23.14, U23.26, U23.30, U23.53, U23.56, U23.57, U23.58, U23.59, U23.60, U23.61, U23.62, U23.63, U23.64, U23.65, U23.66, U23.67, U23.68, U23.69, U23.70, U23.71, U24.2, U25.2, U26.1, U26.4, U26.6, U26.9, U27.1, U27.5, U27.7, U28.P2, U28.P3, U28.P6, U28.P7
GND4: C65.2, C66.2, C67.2, C68.2, C69.2, C70.2, C71.2, C72.2, C73.2, C74.2, C75.2, C76.2, C77.2, C78.2, C79.2, C80.2, D23.GND, D24.C, D25.C, J25.25, J26.GND, J26.GND2, J27.1, J28.6, J28.GND1, J28.GND2, J28.GND3, J28.GND4, J28.GND5, J28.GND6, J29.5, J30.1, R53.1, R54.1, R56.1, R57.1, S5.1, S5.2, SHLD4.1, U29.2, U30.6, U30.12, U30.14, U30.26, U30.30, U30.53, U30.56, U30.57, U30.58, U30.59, U30.60, U30.61, U30.62, U30.63, U30.64, U30.65, U30.66, U30.67, U30.68, U30.69, U30.70, U30.71, U31.2, U32.2, U33.1, U33.4, U33.6, U33.9, U34.1, U34.5, U34.7, U35.P2, U35.P3, U35.P6, U35.P7
GND5: C81.2, C82.2, C83.2, C84.2, C85.2, C86.2, C87.2, C88.2, C89.2, C90.2, C91.2, C92.2, C93.2, C94.2, C95.2, C96.2, D28.GND, D29.C, D30.C, J31.25, J32.GND, J32.GND2, J33.1, J34.6, J34.GND1, J34.GND2, J34.GND3, J34.GND4, J34.GND5, J34.GND6, J35.5, J36.1, R66.1, R67.1, R69.1, R70.1, S6.1, S6.2, SHLD5.1, U36.2, U37.6, U37.12, U37.14, U37.26, U37.30, U37.53, U37.56, U37.57, U37.58, U37.59, U37.60, U37.61, U37.62, U37.63, U37.64, U37.65, U37.66, U37.67, U37.68, U37.69, U37.70, U37.71, U38.2, U39.2, U40.1, U40.4, U40.6, U40.9, U41.1, U41.5, U41.7, U42.P2, U42.P3, U42.P6, U42.P7
GND6: C97.2, C98.2, C99.2, C100.2, C101.2, C102.2, C103.2, C104.2, C105.2, C106.2, C107.2, C108.2, C109.2, C110.2, C111.2, C112.2, D33.GND, D34.C, D35.C, J37.25, J38.GND, J38.GND2, J39.1, J40.6, J40.GND1, J40.GND2, J40.GND3, J40.GND4, J40.GND5, J40.GND6, J41.5, J42.1, R79.1, R80.1, R82.1, R83.1, S7.1, S7.2, SHLD6.1, U43.2, U44.6, U44.12, U44.14, U44.26, U44.30, U44.53, U44.56, U44.57, U44.58, U44.59, U44.60, U44.61, U44.62, U44.63, U44.64, U44.65, U44.66, U44.67, U44.68, U44.69, U44.70, U44.71, U45.2, U46.2, U47.1, U47.4, U47.6, U47.9, U48.1, U48.5, U48.7, U49.P2, U49.P3, U49.P6, U49.P7
GND7: C113.2, C114.2, C115.2, C116.2, C117.2, C118.2, C119.2, C120.2, C121.2, C122.2, C123.2, C124.2, C125.2, C126.2, C127.2, C128.2, D38.GND, D39.C, D40.C, J43.25, J44.GND, J44.GND2, J45.1, J46.6, J46.GND1, J46.GND2, J46.GND3, J46.GND4, J46.GND5, J46.GND6, J47.5, J48.1, R92.1, R93.1, R95.1, R96.1, S8.1, S8.2, SHLD7.1, U50.2, U51.6, U51.12, U51.14, U51.26, U51.30, U51.53, U51.56, U51.57, U51.58, U51.59, U51.60, U51.61, U51.62, U51.63, U51.64, U51.65, U51.66, U51.67, U51.68, U51.69, U51.70, U51.71, U52.2, U53.2, U54.1, U54.4, U54.6, U54.9, U55.1, U55.5, U55.7, U56.P2, U56.P3, U56.P6, U56.P7
GND8: C129.2, C130.2, C131.2, C132.2, C133.2, C134.2, C135.2, C136.2, C137.2, C138.2, C139.2, C140.2, C141.2, C142.2, C143.2, C144.2, D43.GND, D44.C, D45.C, J49.25, J50.GND, J50.GND2, J51.1, J52.6, J52.GND1, J52.GND2, J52.GND3, J52.GND4, J52.GND5, J52.GND6, J53.5, J54.1, R105.1, R106.1, R108.1, R109.1, S9.1, S9.2, SHLD8.1, U57.2, U58.6, U58.12, U58.14, U58.26, U58.30, U58.53, U58.56, U58.57, U58.58, U58.59, U58.60, U58.61, U58.62, U58.63, U58.64, U58.65, U58.66, U58.67, U58.68, U58.69, U58.70, U58.71, U59.2, U60.2, U61.1, U61.4, U61.6, U61.9, U62.1, U62.5, U62.7, U63.P2, U63.P3, U63.P6, U63.P7
GND9: C145.2, C146.2, C147.2, C148.2, C149.2, C150.2, C151.2, C152.2, C153.2, C154.2, C155.2, C156.2, C157.2, C158.2, C159.2, C160.2, D48.GND, D49.C, D50.C, J55.25, J56.GND, J56.GND2, J57.1, J58.6, J58.GND1, J58.GND2, J58.GND3, J58.GND4, J58.GND5, J58.GND6, J59.5, J60.1, R118.1, R119.1, R121.1, R122.1, S10.1, S10.2, SHLD9.1, U64.2, U65.6, U65.12, U65.14, U65.26, U65.30, U65.53, U65.56, U65.57, U65.58, U65.59, U65.60, U65.61, U65.62, U65.63, U65.64, U65.65, U65.66, U65.67, U65.68, U65.69, U65.70, U65.71, U66.2, U67.2, U68.1, U68.4, U68.6, U68.9, U69.1, U69.5, U69.7, U70.P2, U70.P3, U70.P6, U70.P7
IO1/GPIO1: J2.8, U2.1
IO1/GPIO2: J7.8, U9.1
IO1/GPIO3: J13.8, U16.1
IO1/GPIO4: J19.8, U23.1
IO1/GPIO5: J25.8, U30.1
IO1/GPIO6: J31.8, U37.1
IO1/GPIO7: J37.8, U44.1
IO1/GPIO8: J43.8, U51.1
IO1/GPIO9: J49.8, U58.1
IO1/GPIO10: J55.8, U65.1
IO2/GPIO1: J7.7, U9.2
IO2/GPIO2: J2.7, U2.2
IO2/GPIO3: J13.7, U16.2
IO2/GPIO4: J19.7, U23.2
IO2/GPIO5: J25.7, U30.2
IO2/GPIO6: J31.7, U37.2
IO2/GPIO7: J37.7, U44.2
IO2/GPIO8: J43.7, U51.2
IO2/GPIO9: J49.7, U58.2
IO2/GPIO10: J55.7, U65.2
IO3/GPIO1: J7.6, U9.3
IO3/GPIO2: J13.6, U16.3
IO3/GPIO3: J2.6, U2.3
IO3/GPIO4: J19.6, U23.3
IO3/GPIO5: J25.6, U30.3
IO3/GPIO6: J31.6, U37.3
IO3/GPIO7: J37.6, U44.3
IO3/GPIO8: J43.6, U51.3
IO3/GPIO9: J49.6, U58.3
IO3/GPIO10: J55.6, U65.3
IO4/GPIO1: J7.5, U9.4
IO4/GPIO2: J13.5, U16.4
IO4/GPIO3: J19.5, U23.4
IO4/GPIO4: J2.5, U2.4
IO4/GPIO5: J25.5, U30.4
IO4/GPIO6: J31.5, U37.4
IO4/GPIO7: J37.5, U44.4
IO4/GPIO8: J43.5, U51.4
IO4/GPIO9: J49.5, U58.4
IO4/GPIO10: J55.5, U65.4
IO5/NINA_RX/DEV_TX: J2.15, U2.5
IO5/NINA_RX/DEV_TX1: J7.15, U9.5
IO5/NINA_RX/DEV_TX2: J13.15, U16.5
IO5/NINA_RX/DEV_TX3: J19.15, U23.5
IO5/NINA_RX/DEV_TX4: J25.15, U30.5
IO5/NINA_RX/DEV_TX5: J31.15, U37.5
IO5/NINA_RX/DEV_TX6: J37.15, U44.5
IO5/NINA_RX/DEV_TX7: J43.15, U51.5
IO5/NINA_RX/DEV_TX8: J49.15, U58.5
IO5/NINA_RX/DEV_TX9: J55.15, U65.5
IO7/NINA_TX/DEV_RX: J2.14, U2.7
IO7/NINA_TX/DEV_RX1: J7.14, U9.7
IO7/NINA_TX/DEV_RX2: J13.14, U16.7
IO7/NINA_TX/DEV_RX3: J19.14, U23.7
IO7/NINA_TX/DEV_RX4: J25.14, U30.7
IO7/NINA_TX/DEV_RX5: J31.14, U37.7
IO7/NINA_TX/DEV_RX6: J37.14, U44.7
IO7/NINA_TX/DEV_RX7: J43.14, U51.7
IO7/NINA_TX/DEV_RX8: J49.14, U58.7
IO7/NINA_TX/DEV_RX9: J55.14, U65.7
IO17/A1: J7.19, U9.17
IO17/A2: J13.19, U16.17
IO17/A3: J19.19, U23.17
IO17/A4: J25.19, U30.17
IO17/A5: J2.19, U2.17
IO17/A6: J31.19, U37.17
IO17/A7: J37.19, U44.17
IO17/A8: J43.19, U51.17
IO17/A9: J49.19, U58.17
IO17/A10: J55.19, U65.17
IO18/A1: J7.20, U9.18
IO18/A2: J13.20, U16.18
IO18/A3: J19.20, U23.18
IO18/A4: J2.20, U2.18
IO18/A5: J25.20, U30.18
IO18/A6: J31.20, U37.18
IO18/A7: J37.20, U44.18
IO18/A8: J43.20, U51.18
IO18/A9: J49.20, U58.18
IO18/A10: J55.20, U65.18
IO20/A1: J7.21, U9.20
IO20/A2: J13.21, U16.20
IO20/A3: J2.21, U2.20
IO20/A4: J19.21, U23.20
IO20/A5: J25.21, U30.20
IO20/A6: J31.21, U37.20
IO20/A7: J37.21, U44.20
IO20/A8: J43.21, U51.20
IO20/A9: J49.21, U58.20
IO20/A10: J55.21, U65.20
IO21/IMU_INT1: TP8.1, U2.21, U6.P4
IO21/IMU_INT2: TP11.1, U9.21, U14.P4
IO21/IMU_INT3: TP18.1, U16.21, U21.P4
IO21/IMU_INT4: TP25.1, U23.21, U28.P4
IO21/IMU_INT5: TP32.1, U30.21, U35.P4
IO21/IMU_INT6: TP39.1, U37.21, U42.P4
IO21/IMU_INT7: TP46.1, U44.21, U49.P4
IO21/IMU_INT8: TP53.1, U51.21, U56.P4
IO21/IMU_INT9: TP60.1, U58.21, U63.P4
IO21/IMU_INT10: TP67.1, U65.21, U70.P4
IO22/IMU_INT1: TP12.1, U9.22, U14.P9
IO22/IMU_INT2: TP9.1, U2.22, U6.P9
IO22/IMU_INT3: TP19.1, U16.22, U21.P9
IO22/IMU_INT4: TP26.1, U23.22, U28.P9
IO22/IMU_INT5: TP33.1, U30.22, U35.P9
IO22/IMU_INT6: TP40.1, U37.22, U42.P9
IO22/IMU_INT7: TP47.1, U44.22, U49.P9
IO22/IMU_INT8: TP54.1, U51.22, U56.P9
IO22/IMU_INT9: TP61.1, U58.22, U63.P9
IO22/IMU_INT10: TP68.1, U65.22, U70.P9
IO23/A1: J2.23, U2.23
IO23/A2: J7.23, U9.23
IO23/A3: J13.23, U16.23
IO23/A4: J19.23, U23.23
IO23/A5: J25.23, U30.23
IO23/A6: J31.23, U37.23
IO23/A7: J37.23, U44.23
IO23/A8: J43.23, U51.23
IO23/A9: J49.23, U58.23
IO23/A10: J55.23, U65.23
IO24/A0: J2.24, U2.24
IO24/A1: J7.24, U9.24
IO24/A2: J13.24, U16.24
IO24/A3: J19.24, U23.24
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

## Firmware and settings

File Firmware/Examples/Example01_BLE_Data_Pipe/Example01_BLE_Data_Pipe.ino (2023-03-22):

/*
  BLE Data Pipe
  
  This example creates a BLE peripheral with a sensor service using the 
  SparkFun NINA-B306 Thing Plus. The sensor service notifies (push data to) the
  central.
  
  The sensor service contains the following characteristics:
  Acceleration X,Y,Z
  Gyro X,Y,Z
  Temperature (degC), Humidity, Pressure

  MIT License

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
*/

#include <Wire.h>
#include <Adafruit_TinyUSB.h>

#include <SparkFunBME280.h>
#include <SparkFun_ISM330DHCX.h>
#include <SparkFun_MAX1704x_Fuel_Gauge_Arduino_Library.h>

#include "bluefruit.h"
#include "SparkFunBLEService.h"
#include "services/SparkFunBLE_ISM330DHCX.h"
#include "services/SparkFunBLE_BME280.h"


/* Battery Monitor */
SFE_MAX1704X              lipo(MAX1704X_MAX17048);

long curr_millis    = 0;
long prev_millis    = 0;
long batt_interval  = 5000; // 5s in ms

/* BME280 Environmental Sensor */
BME280                    envSensor;

/* ISM330DHCX 6-DoF IMU Sensor */
SparkFun_ISM330DHCX       imuSensor;

sfe_ism_data_t _accelData;
sfe_ism_data_t _gyroData;

/* IMU BLE Service */
SparkFunBLE_ISM330DHCX    bleIMU;

/* ENV BLE Service */
SparkFunBLE_BME280        bleENV;

/* BLE Device Information
 * Name - Thing Plus NINA-B306 Data Pipe
 * Manufacturer - SparkFun Electronics
 * Model - SparkFun Thing Plus NINA-B306
 */
BLEDis                    bledis;

/* BLE Battery Service helper class */
BLEBas                    blebas;

void setup() {
  Serial.begin(115200);
  //while(!Serial) delay(10);

  Serial.println(F("SparkFun BLE Data Pipe Example"));
  Serial.println(F("------------------------------\n"));

  Wire.begin();

  // Initialize Sensors
  initFuelGauge();

  initBME280();

  initISM330DHCX();

  //Initialize BLE things
  Bluefruit.begin();
  Bluefruit.setTxPower(8); // +8 dBm, max power.
  Bluefruit.setName("Data Pipe Example");

  // Configure and start Device Information Service
  Serial.println(F("Configuring the Device Information Service..."));
  bledis.setManufacturer("SparkFun Electronics");
  bledis.setModel("Thing Plus NINA-B306");
  bledis.setHardwareRev("v10");
  bledis.setSoftwareRev("0.1.0");
  bledis.begin();

  // Configure and start BLE Battery Service and initialize to 100%
  Serial.println(F("Configuring the Battery Service..."));
  blebas.begin();
  blebas.write(100);

  // Configure and start BLE Environmental Sensor Service
  // Make sure to give enough room between sensor IDs, the BME280 uses 3 IDs.
  Serial.println(F("Configuring the Environmental Sensor Service..."));
  bleENV.begin(&envSensor, 100); // Sensor, ID.


  // Configure and start the IMU Sensor Service
  // Make sure to give enough room between sensor IDs, the IMU uses 2 IDs.
  Serial.println(F("Configuring the IMU Data Service..."));
  bleIMU.begin(&imuSensor, 200); // Sensor, ID.
  

  Serial.println(F("Setup complete."));
  
  /*  Start advertising BLE. It will start continuously transmitting BLE
      advertising packets and will be visible to remote BLE central devices
      until it receives a connection.  
  */
  startAdv();

  Serial.println(F("BLE device active, waiting for connections..."));

}

void loop() {

  // Battery service handler
  curr_millis = millis();
  if ((curr_millis - prev_millis) > batt_interval) { // check every batt_interval ms
    prev_millis = curr_millis;
    if ( lipo.isChange(true) ) {  // only update if battery SOC is > +/- 1%
      blebas.write(lipo.getSOC());
    }
  }

}

void startAdv() {
  Serial.println(F("Begin advertising."));
  Bluefruit.Advertising.addFlags(BLE_GAP_ADV_FLAGS_LE_ONLY_GENERAL_DISC_MODE);
  Bluefruit.Advertising.addTxPower();

  // Add services
  Bluefruit.Advertising.addService(bleENV, bleIMU);
  
  Bluefruit.ScanResponse.addName();

  /* Start Advertising
   * - Enable auto advertising if disconnected
   * - Interval: fast mode = 20 ms, slow mode = 152.5 ms
   * - Timeout for fast mode is 30 seconds
   * - Start(timeout) with timeout = 0 will advertise forever (until connected)
   * 
   * For recommended advertising interval
   * https://developer.apple.com/library/content/qa/qa1931/_index.html
   */
  Bluefruit.Advertising.restartOnDisconnect(true);
  Bluefruit.Advertising.setInterval(32, 244);       // units of 0.625 ms
  Bluefruit.Advertising.setFastTimeout(30);         // number of seconds in fast mode
  Bluefruit.Advertising.start(0);                   // 0 = Don't stop advertising unless connected

}

void initFuelGauge() {
  Serial.println(F("Initializing MAX17048 Battery Fuel Gauge..."));

  if (!lipo.begin()) {
    Serial.println(F("MAX17048 not detected. Please check wiring. Freezing."));
    while(1);
  }

  // Read and print the battery threshold
  Serial.print(F("Battery empty threshold is currently: "));
  Serial.print(lipo.getThreshold());
  Serial.println(F("%"));

	// We can set an interrupt to alert when the battery SoC gets too low.
	// We can alert at anywhere between 1% and 32%:
	lipo.setThreshold(20); // Set alert threshold to 20%.

  // Read and print the battery empty threshold
  Serial.print(F("Battery empty threshold is now: "));
  Serial.print(lipo.getThreshold());
  Serial.println(F("%"));
  
  // Clear any alert that might already be generated.
  lipo.clearAlert();

}

void initBME280() {
  Serial.println("Initializing BME280 Environmental Sensor...");
  envSensor.setI2CAddress(0x76); // Default address on NINA-B306

  if (!envSensor.beginI2C()) {
    Serial.println("The BME280 did not respond. Please check address and wiring.");
    while(1);
  }
  Serial.println("BME280 initialization successful.");
}

void initISM330DHCX() {
  Serial.println("Initializing ISM330DHCX...");

  if (!imuSensor.begin()) {
    Serial.println("The ISM330DHCX did not respond. Please check address and wiring.");
    while(1);
  }

  Serial.println("ISM330DHCX Initialization successful. Resetting device settings...");

  imuSensor.deviceReset();

  while(!imuSensor.getDeviceReset()){
    delay(1);
  }
    
  Serial.println("Device reset complete. Configuring ISM330DHCX...");
  delay(100);

  imuSensor.setDeviceConfig();
  imuSensor.setBlockDataUpdate();

  // Set accelerometer output data rate and data precision
  imuSensor.setAccelDataRate(ISM_XL_ODR_104Hz);
  imuSensor.setAccelFullScale(ISM_4g);

  // Set gyro output data rate and data precision
  imuSensor.setGyroDataRate(ISM_GY_ODR_104Hz);
  imuSensor.setGyroFullScale(ISM_500dps);

  // Turn on accelerometer's filter and apply settings.
  imuSensor.setAccelFilterLP2();
  imuSensor.setAccelSlopeFilter(ISM_LP_ODR_DIV_100);

  // Turn on gyro's filter and apply settings.
  imuSensor.setGyroFilterLP1();
  imuSensor.setGyroLP1Bandwidth(ISM_MEDIUM);

  Serial.println("ISM330DHCX successfully configured.");
}

uint16_t measureCallBack(uint8_t* buf, uint16_t bufsize) {
  float imu_data[6];
  imuSensor.getAccel(&_accelData);
  imuSensor.getGyro(&_gyroData);

  imu_data[0] = _accelData.xData * 0.0098067;
  imu_data[1] = _accelData.yData * 0.0098067;
  imu_data[2] = _accelData.zData * 0.0098067;
  imu_data[3] = _gyroData.xData * 0.017453;
  imu_data[4] = _gyroData.yData * 0.017453;
  imu_data[5] = _gyroData.zData * 0.017453;

  memcpy(buf, &imu_data, 24);

  return 24;
}

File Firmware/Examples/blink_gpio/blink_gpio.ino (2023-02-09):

#include <Arduino.h>
#include <Adafruit_TinyUSB.h>

void setup() {
  pinMode(0, OUTPUT);
  pinMode(1, OUTPUT);
  pinMode(2, OUTPUT);
  pinMode(3, OUTPUT);
  pinMode(4, OUTPUT);
  pinMode(5, OUTPUT);
  pinMode(6, OUTPUT);
  pinMode(7, OUTPUT);
  pinMode(8, OUTPUT);
  pinMode(9, OUTPUT);
  pinMode(10, OUTPUT);
  pinMode(11, OUTPUT);
  pinMode(12, OUTPUT);
  pinMode(13, OUTPUT);
  pinMode(14, OUTPUT);
  pinMode(15, OUTPUT);
  pinMode(16, OUTPUT);
  pinMode(17, OUTPUT);
  pinMode(18, OUTPUT);
  pinMode(19, OUTPUT);
  pinMode(27, OUTPUT);

  Serial.begin(115200);
  while(!Serial){
    yield();
  };
  Serial.println("Beginning GPIO test at top left, moving down, then across and back up.\n");
}

void loop() {
  digitalWrite(3, HIGH);
  delay(100);
  digitalWrite(3, LOW);
  delay(50);
  digitalWrite(4, HIGH);
  delay(100);
  digitalWrite(4, LOW);
  delay(50);
  digitalWrite(5, HIGH);
  delay(100);
  digitalWrite(5, LOW);
  delay(50);
  digitalWrite(6, HIGH);
  delay(100);
  digitalWrite(6, LOW);
  delay(50);
  digitalWrite(9, HIGH);
  delay(100);
  digitalWrite(9, LOW);
  delay(50);
  digitalWrite(10, HIGH);
  delay(100);
  digitalWrite(10, LOW);
  delay(50);
  digitalWrite(11, HIGH);
  delay(100);
  digitalWrite(11, LOW);
  delay(50);
  digitalWrite(12, HIGH);
  delay(100);
  digitalWrite(12, LOW);
  delay(50);
  digitalWrite(13, HIGH);
  delay(100);
  digitalWrite(13, LOW);
  delay(50);
  digitalWrite(14, HIGH);
  delay(100);
  digitalWrite(14, LOW);
  delay(50);
  digitalWrite(15, HIGH);
  delay(100);
  digitalWrite(15, LOW);
  delay(50);
  digitalWrite(16, HIGH);
  delay(100);
  digitalWrite(16, LOW);
  delay(50);
  digitalWrite(17, HIGH);
  delay(100);
  digitalWrite(17, LOW);
  delay(50);
  digitalWrite(18, HIGH);
  delay(100);
  digitalWrite(18, LOW);
  delay(50);
  digitalWrite(19, HIGH);
  delay(100);
  digitalWrite(19, LOW);
  delay(50);
  digitalWrite(27, HIGH);
  delay(100);
  digitalWrite(27, LOW);
  delay(50);
  digitalWrite(7, HIGH);
  delay(100);
  digitalWrite(7, LOW);
  delay(50);
  digitalWrite(8, HIGH);
  delay(100);
  digitalWrite(8, LOW);
  delay(50);
  digitalWrite(0, HIGH);
  delay(100);
  digitalWrite(0, LOW);
  delay(50);
  digitalWrite(1, HIGH);
  delay(100);
  digitalWrite(1, LOW);
  delay(50);
  digitalWrite(2, HIGH);
  delay(100);
  digitalWrite(2, LOW);
  delay(50);
}

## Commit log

2022-08-11 First draft schematic, initial pcb layout.
    [SparkFun_Thing_Plus_NINA-B306.brd, SparkFun_Thing_Plus_NINA-B306.sch]
2022-08-15 Updates in prep for sch review
    Schematic: Replaced 0603 10ks with 0402T package.
    Board: Initial layout of parts complete.
    [SparkFun_Thing_Plus_NINA-B306.brd, SparkFun_Thing_Plus_NINA-B306.sch]
2022-08-15 Changed package of 100R, rearrange board.
    Changed 100R from 0603 to 0402T and rearranged the board to better organize that circuit. Also moved the QWIIC logo next to the QWIIC connector with the new space.
    [SparkFun_Thing_Plus_NINA-B306.brd, SparkFun_Thing_Plus_NINA-B306.sch]
2022-08-15 Added net classing, net names.
    [SparkFun_Thing_Plus_NINA-B306.brd, SparkFun_Thing_Plus_NINA-B306.sch]
2022-08-15 Update netclasses and board thickness.
    [SparkFun_Thing_Plus_NINA-B306.brd, SparkFun_Thing_Plus_NINA-B306.sch]
2022-08-15 Routed high speed and analog.
    [SparkFun_Thing_Plus_NINA-B306.brd, SparkFun_Thing_Plus_NINA-B306.sch]
2022-08-19 Routing, end of week commit.
    [SparkFun_Thing_Plus_NINA-B306.brd, SparkFun_Thing_Plus_NINA-B306.sch]
2022-08-31 routed and ready for v01 design review.
    [SparkFun_Thing_Plus_NINA-B306-Panel.GBL, SparkFun_Thing_Plus_NINA-B306-Panel.GBO, SparkFun_Thing_Plus_NINA-B306-Panel.GBP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]
2022-09-06 v01 ready for production.
    Move Power LED
    Move MEAS jumper
    Move GPIO6 to a new IO pin
    Remove Q2
    Allow ground pour between IO41 and SDA
    Add vias next to BME280 ground pad
    Shorten !RESET! top silk to !RST!
    Swap CHG silk vertical direction
    Add IMU silk from ISM BOB
    Add more ground vias
    Rotate !RST! on bottom silk
    Reset button silk
    LED silk
    Add "NINA-B306" under module on top silk
    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
    [SparkFun_Thing_Plus_NINA-B306-Panel.brd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]
2022-12-12 Update for v10 post-proto changes.
    Add CHG LED silk
    Flip silk text direction on rear !RST!
    Change GPIO6/IO35 silk
    Add silk for first pin on SWD pogo
    Re-place updated ESD diode.
    [SparkFun_Thing_Plus_NINA-B306.brd, SparkFun_Thing_Plus_NINA-B306.sch]
2022-12-19 Added Layer numbers
    [SparkFun_Thing_Plus_NINA-B306-Panel.GBL, SparkFun_Thing_Plus_NINA-B306-Panel.GBO, SparkFun_Thing_Plus_NINA-B306-Panel.GBP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]
2022-12-19 Moved files to proper spot.
    [SparkFun_Thing_Plus_NINA-B306-Panel.GBL, SparkFun_Thing_Plus_NINA-B306-Panel.GBO, SparkFun_Thing_Plus_NINA-B306-Panel.GBP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]
2023-03-04 Add wrapper classes for sensors to map to Adafruit_Sensor class.
2023-03-04 Add SparkFunBLE Sensor Services for onboard devices.
2023-03-07 Refactor IMU sensor service. Rolls ACC/GYRO into one service creates two instances of Wrapper class. Both wrappers point to the same sensor, but different sensors.
2023-03-07 Refactor ENV sensor. Provides one BLE service that creates 3 instances of a wrapper. Each wrapper points to one aspect of the same sensor.
2023-03-08 Added missing header to generic Sensor header.
2023-03-08 Update IMU BLE Service.
    Added correct headers.
    Changed name of data UUID.
    Swapped Adafruit_Sensor to Wrapper class.
    Added objects so they aren't there temporarily.
    Pointer fun.
2023-03-08 Update BME280 BLE Service
    Added missing headers.
    Removed readSensor function, it's now done inside the wrapper.
    Removed the need to have a pointer to sensor measurements at this level.
    Moved Adafruit_Sensor pointers to the correct Wrapper class.
    Removed sensor measurement pointer.
    Added Wrapper objects.
    Pointer fun to make sure wrappers aren't dropped.
2023-03-20 Update Example01_BLE_Data_Pipe.ino
    Removed Serial print statements.
    Removed old unused code.
    Added Service Advertising.
    Added Battery update check.
2023-03-20 Update ISM wrapper
    Removed print statements.
    Reformatted code.
2023-03-20 Update BME wrapper
    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
2023-03-20 Update ISM service.
    Reformat code.
    Modified measure handler to properly post data.
    Added callbacks.
    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
2023-03-20 Update BME Service.
    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
2023-03-23 Moved library to board repo so it's automatically included. Updated readme.

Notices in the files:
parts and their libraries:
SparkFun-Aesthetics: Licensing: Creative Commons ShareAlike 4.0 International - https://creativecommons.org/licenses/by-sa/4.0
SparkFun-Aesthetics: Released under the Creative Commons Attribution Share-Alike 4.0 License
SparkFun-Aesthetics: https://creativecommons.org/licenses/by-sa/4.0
